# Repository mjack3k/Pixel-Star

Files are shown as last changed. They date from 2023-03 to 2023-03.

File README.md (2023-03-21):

# Pixel-Star
PCB star with RGB LEDs, xmas decoration

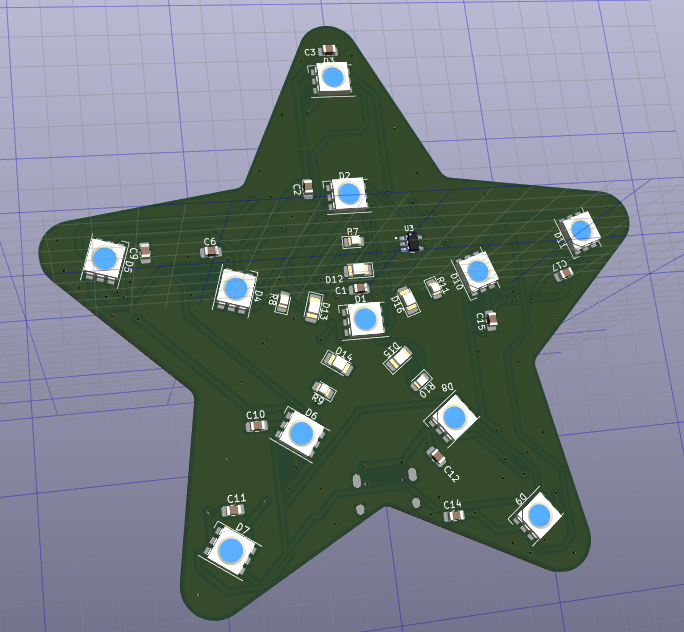
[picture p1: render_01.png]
PCB Render Kicad PCB 3D-render


With this project you can make a simple yet nice star-shaped PCB with a bunch of addressable LEDs.

It has STM32 microcontroller on board and this project provides software for it to drive the LEDs.
<br/><br/><br/>

In order to make it:

1. Download KiCAD 6, STM32CubeIDE, clone/download this project
2. Generate Gerber files according to your manufarcturer rules (for example [JLCPCB](https://support.jlcpcb.com/article/194-how-to-generate-gerber-and-drill-files-in-kicad-6))
3. Order the PCB
4. Order the parts (Kicad project contains links to all parts on lcsc)
5. Solder everything
6. Compile the STM32 project
7. Flash the firmware using ST-Link

A cable with 4-pin molex picoblade connector is needed to flash the board. 
[Like this one here](https://www.ebay.de/itm/174533296900)
<br/><br/><br/>

A quick test of the board:

Pixel-Star on Youtube (https://www.youtube.com/watch?v=iGwG598rLek)

<br/><br/><br/>

### Bill of Materials

|  Pos. | Name  | Link  | Amount  |
| --- | --- | --- | --- |
| 1.  | Capacitor 10µF 1206  | [Link](https://www.lcsc.com/product-detail/Multilayer-Ceramic-Capacitors-MLCC-SMD-SMT_Samsung-Electro-Mechanics-CL31B106KAHNNNE_C14860.html)  |  2  |
| 2.  | Capacitor 100nf 0805  | [Link](https://www.lcsc.com/product-detail/Multilayer-Ceramic-Capacitors-MLCC-SMD-SMT_CCTC-TCC0805X7R104K500DT_C282732.html)  | 17  |
| 3.  | Capacitor 4.7µF 1206  | [Link](https://www.lcsc.com/product-detail/Multilayer-Ceramic-Capacitors-MLCC-SMD-SMT_Samwha-Capacitor-CS3216X7R475K160NRI_C5189824.html)  | 1  |
| 4.  | WS2813E RGB LED  | [Link](https://www.lcsc.com/product-detail/Light-Emitting-Diodes-LED_Worldsemi-WS2813E_C160214.html)  | 11  |
| 5.  | LED 1206 Emerald  | [Link](https://www.lcsc.com/product-detail/Light-Emitting-Diodes-LED_XINGLIGHT-XL-3216UGC_C965825.html)  | 5  |
| 6.  | USB-C Connector  | [Link](https://www.lcsc.com/product-detail/USB-Connectors_SHOU-HAN-TYPE-C-16PIN-2MD-073_C2765186.html)  | 1  |
| 7.  | Picoblade 1x4 Connector  | [Link](https://www.lcsc.com/product-detail/Wire-To-Board-Wire-To-Wire-Connector_MOLEX-532610471_C240847.html)  | 1  |
| 8.  | Resistor 5.11k 0805  | [Link](https://www.lcsc.com/product-detail/Chip-Resistor-Surface-Mount_UNI-ROYAL-Uniroyal-Elec-0805W8F5111T5E_C46039.html)  | 2  |
| 9.  | Resistor 1k 0805  | [Link](https://www.lcsc.com/product-detail/Chip-Resistor-Surface-Mount_FOJAN-FRC0805F1001TS_C2907232.html)  | 2  |
| 10.  | Resistor 10k 0805  | [Link](https://www.lcsc.com/product-detail/Chip-Resistor-Surface-Mount_UNI-ROYAL-Uniroyal-Elec-0805W8F1002T5E_C17414.html)  | 2  |
| 11.  | Resistor 47 Ohm 0805  | [Link](https://www.lcsc.com/product-detail/Chip-Resistor-Surface-Mount_Walsin-Tech-Corp-WR08X47R0FTL_C168456.html)  | 5  |
| 12.  | Button  | [Link](https://www.lcsc.com/product-detail/Tactile-Switches_Korean-Hroparts-Elec-K2-1107ST-A4DW-06_C118141.html)  | 3  |
| 13.  | Voltage regulator 3.3V  | [Link](https://www.lcsc.com/product-detail/Linear-Voltage-Regulators-LDO_HEERMICR-AMS1117-3-3_C5199435.html)  | 1  |
| 14.  | MCU STM32G030  | [Link](https://www.lcsc.com/product-detail/Microcontroller-Units-MCUs-MPUs-SOCs_STMicroelectronics-STM32G030F6P6TR_C529330.html)  | 1  |
| 15.  | Level shifter  | [Link](https://www.lcsc.com/product-detail/Buffers-Drivers_Texas-Instruments-SN74LV1T34DBVR_C100024.html)  | 1  |

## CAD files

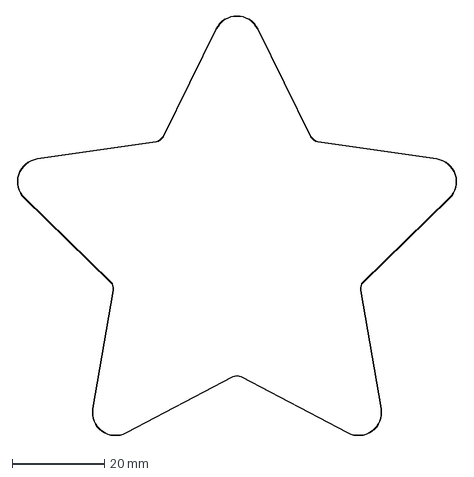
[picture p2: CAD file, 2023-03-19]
kicad/Stern.DXF
96.0 x 91.4 mm

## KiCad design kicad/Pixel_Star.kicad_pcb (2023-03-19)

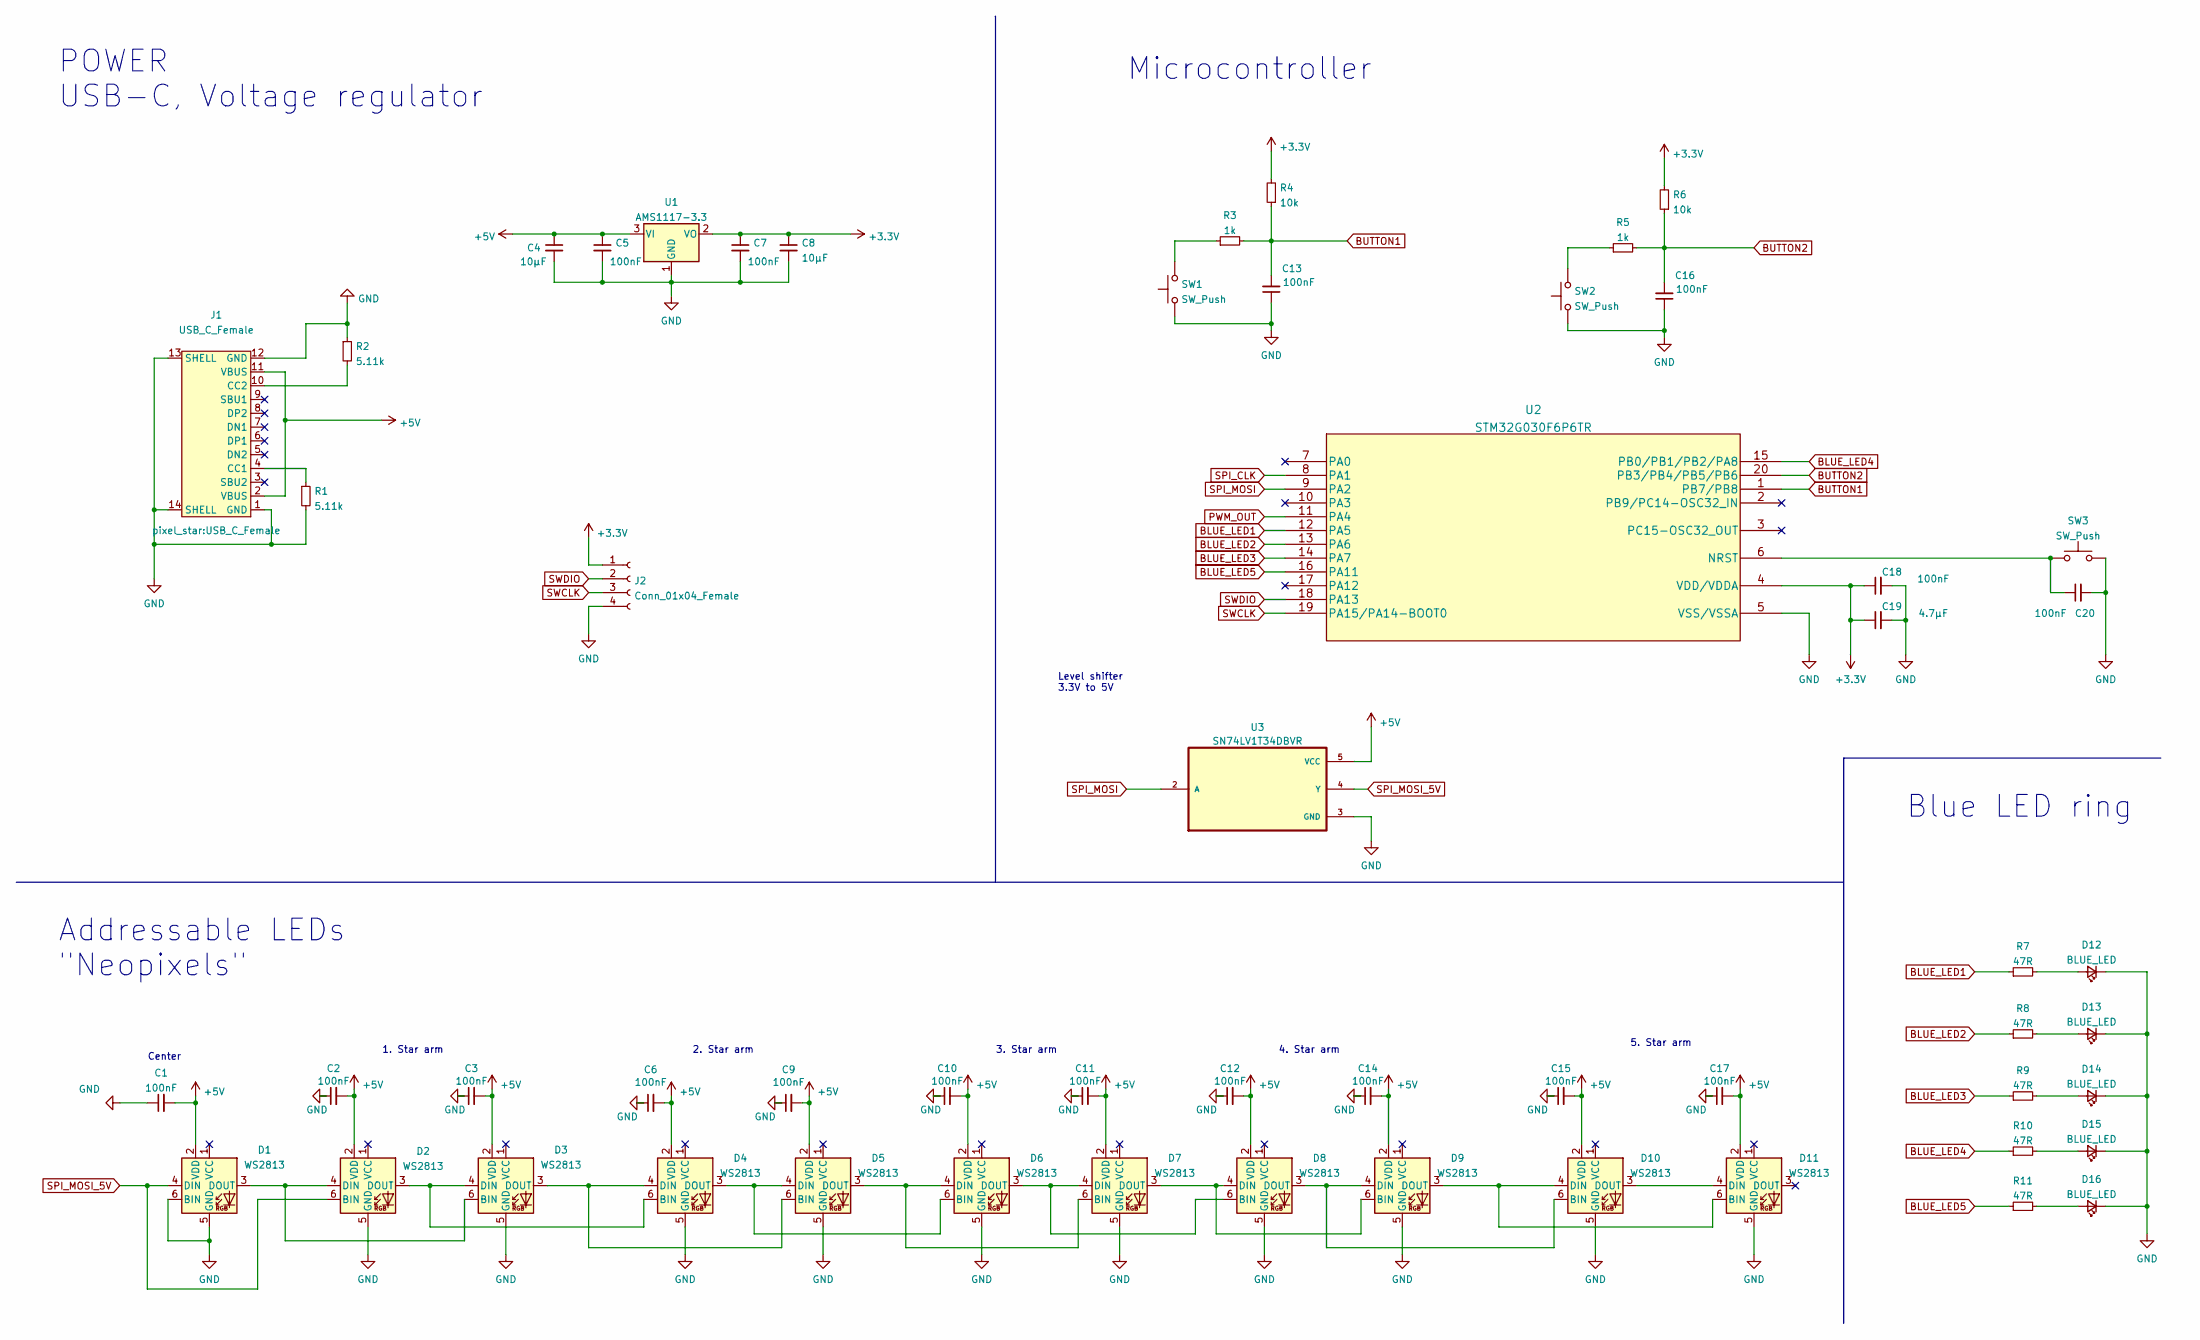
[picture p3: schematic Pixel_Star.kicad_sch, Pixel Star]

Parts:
C1, C2, C3, C5, C6, C7, C9, C10, C11, C12, C13, C14, C15, C16, C17, C18, C20: 100nF; C_0805_2012Metric_Pad1.18x1.45mm_HandSolder
C4, C8: 10µF; C_1206_3216Metric_Pad1.33x1.80mm_HandSolder
C19: 4.7µF; C_1206_3216Metric_Pad1.33x1.80mm_HandSolder
D1, D2, D3, D4, D5, D6, D7, D8, D9, D10, D11: WS2813; LED_WS2812_PLCC6_5.0x5.0mm_P1.6mm
D12, D13, D14, D15, D16: BLUE_LED; LED_1206_3216Metric_Pad1.42x1.75mm_HandSolder
J1: USB_C_Female
J2: Conn_01x04_Female; Molex_PicoBlade_53261-0471_1x04-1MP_P1.25mm_Horizontal
R1, R2: 5.11k; R_0805_2012Metric_Pad1.20x1.40mm_HandSolder
R3, R5: 1k; R_0805_2012Metric_Pad1.20x1.40mm_HandSolder
R4, R6: 10k; R_0805_2012Metric_Pad1.20x1.40mm_HandSolder
R7, R8, R9, R10, R11: 47R; LED_0805_2012Metric_Pad1.15x1.40mm_HandSolder
SW1, SW2, SW3: SW_Push; K2-1107ST-A4DW-06
U1: AMS1117-3.3; SOT-223-3_TabPin2
U2: STM32G030F6P6TR
U3: SN74LV1T34DBVR; SOT95P280X145-5N

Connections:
+3V3: C7.1, C8.1, C18.1, C19.1, J2.1, R4.2, R6.2, U1.2 (VO), U2.4 (VDD/VDDA)
+5V: C1.2, C2.2, C3.2, C4.1, C5.1, C6.2, C9.2, C10.2, C11.2, C12.2, C14.2, C15.2, C17.2, D1.2 (VDD), D2.2 (VDD), D3.2 (VDD), D4.2 (VDD), D5.2 (VDD), D6.2 (VDD), D7.2 (VDD), D8.2 (VDD), D9.2 (VDD), D10.2 (VDD), D11.2 (VDD), J1.2 (VBUS), J1.11 (VBUS), U1.3 (VI), U3.5 (VCC)
BLUE_LED1: R7.1, U2.12 (PA5)
BLUE_LED2: R8.1, U2.13 (PA6)
BLUE_LED3: R9.1, U2.14 (PA7)
BLUE_LED4: R10.1, U2.15 (PB0/PB1/PB2/PA8)
BLUE_LED5: R11.1, U2.16 (PA11)
BUTTON1: C13.2, R3.2, R4.1, U2.1 (PB7/PB8)
BUTTON2: C16.2, R5.2, R6.1, U2.20 (PB3/PB4/PB5/PB6)
GND: C1.1, C2.1, C3.1, C4.2, C5.2, C6.1, C7.2, C8.2, C9.1, C10.1, C11.1, C12.1, C13.1, C14.1, C15.1, C16.1, C17.1, C18.2, C19.2, C20.2, D1.5 (GND), D1.6 (BIN), D2.5 (GND), D3.5 (GND), D4.5 (GND), D5.5 (GND), D6.5 (GND), D7.5 (GND), D8.5 (GND), D9.5 (GND), D10.5 (GND), D11.5 (GND), D12.1 (K), D13.1 (K), D14.1 (K), D15.1 (K), D16.1 (K), J1.1 (GND), J1.12 (GND), J1.13 (SHELL), J1.14 (SHELL), J2.4, R1.2, R2.1, SW1.1, SW2.1, SW3.2, U1.1 (GND), U2.5 (VSS/VSSA), U3.3 (GND)
unnamed: C20.1, SW3.1, U2.6 (NRST)
unnamed: D1.3 (DOUT), D2.4 (DIN), D3.6 (BIN)
unnamed: D2.3 (DOUT), D3.4 (DIN), D4.6 (BIN)
unnamed: D3.3 (DOUT), D4.4 (DIN), D5.6 (BIN)
unnamed: D4.3 (DOUT), D5.4 (DIN), D6.6 (BIN)
unnamed: D5.3 (DOUT), D6.4 (DIN), D7.6 (BIN)
unnamed: D6.3 (DOUT), D7.4 (DIN), D8.6 (BIN)
unnamed: D7.3 (DOUT), D8.4 (DIN), D9.6 (BIN)
unnamed: D10.3 (DOUT), D11.4 (DIN)
unnamed: D9.3 (DOUT), D10.4 (DIN), D11.6 (BIN)
unnamed: D8.3 (DOUT), D9.4 (DIN), D10.6 (BIN)
unnamed: D12.2 (A), R7.2
unnamed: D13.2 (A), R8.2
unnamed: D14.2 (A), R9.2
unnamed: D15.2 (A), R10.2
unnamed: D16.2 (A), R11.2
unnamed: J1.4 (CC1), R1.1
unnamed: J1.10 (CC2), R2.2
unnamed: R3.1, SW1.2
unnamed: R5.1, SW2.2
PWM_OUT: U2.11 (PA4)
SPI_CLK: U2.8 (PA1)
SPI_MOSI: U2.9 (PA2), U3.2 (A)
SPI_MOSI_5V: D1.4 (DIN), D2.6 (BIN), U3.4 (Y)
SWCLK: J2.3, U2.19 (PA15/PA14-BOOT0)
SWDIO: J2.2, U2.18 (PA13)

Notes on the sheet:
Level shifter 3.3V to 5V
Addressable LEDs "Neopixels"
Microcontroller
3. Star arm
Center
Blue LED ring
POWER USB-C, Voltage regulator
4. Star arm
1. Star arm
5. Star arm
2. Star arm

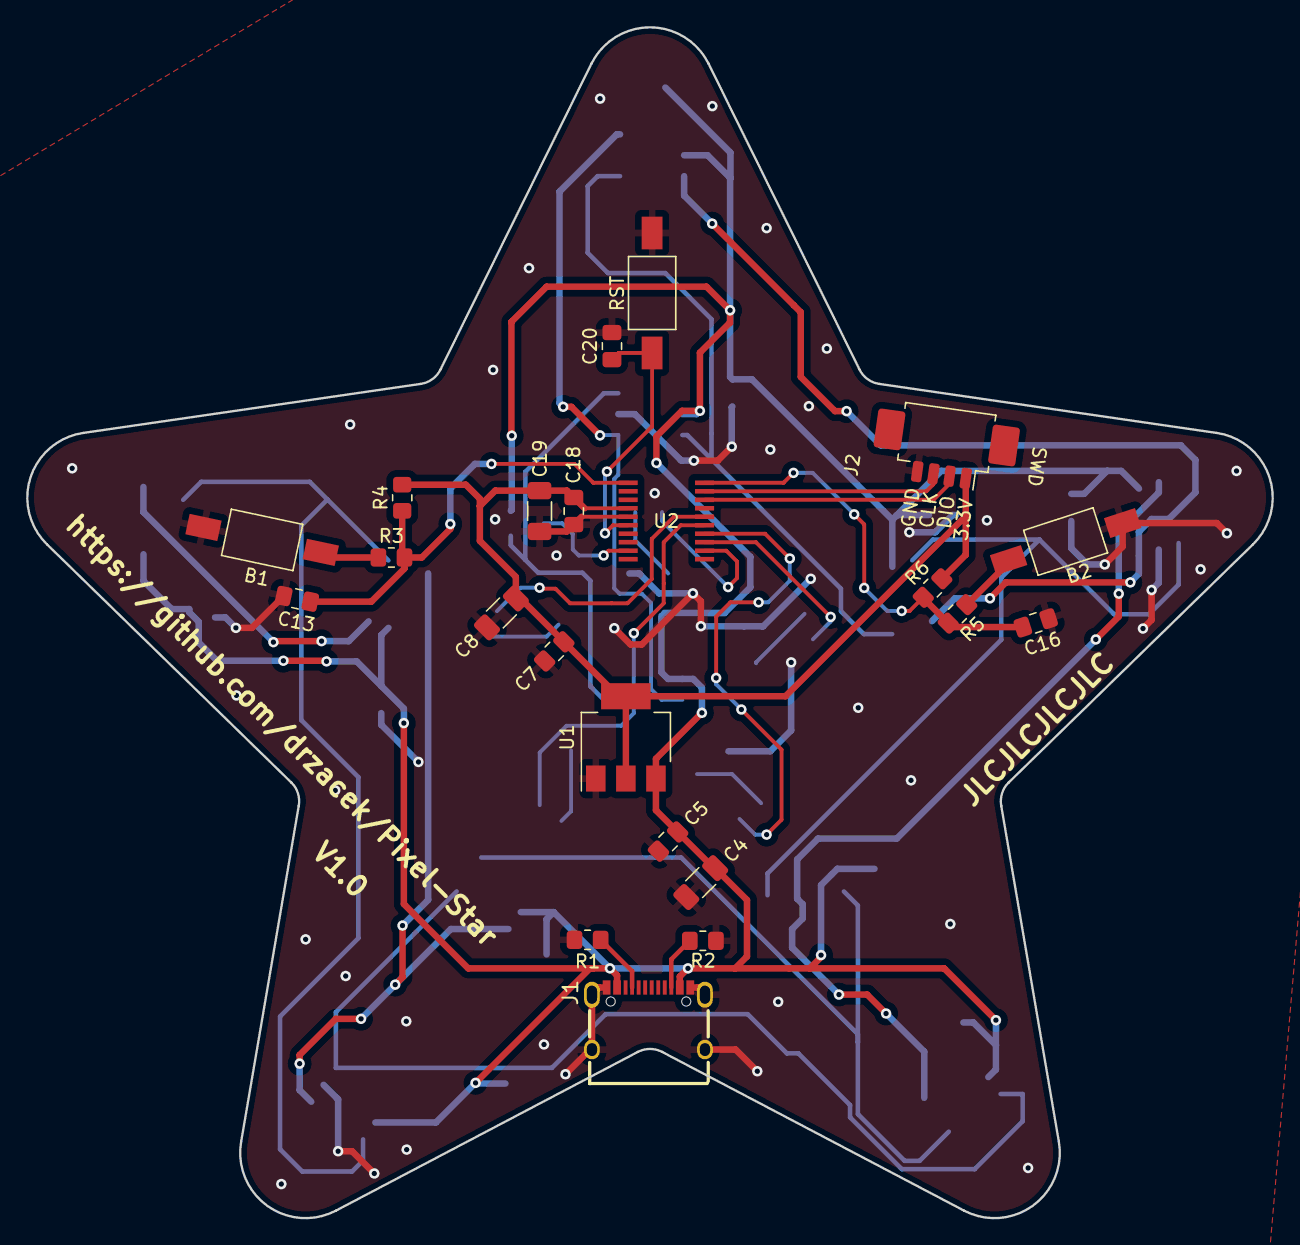
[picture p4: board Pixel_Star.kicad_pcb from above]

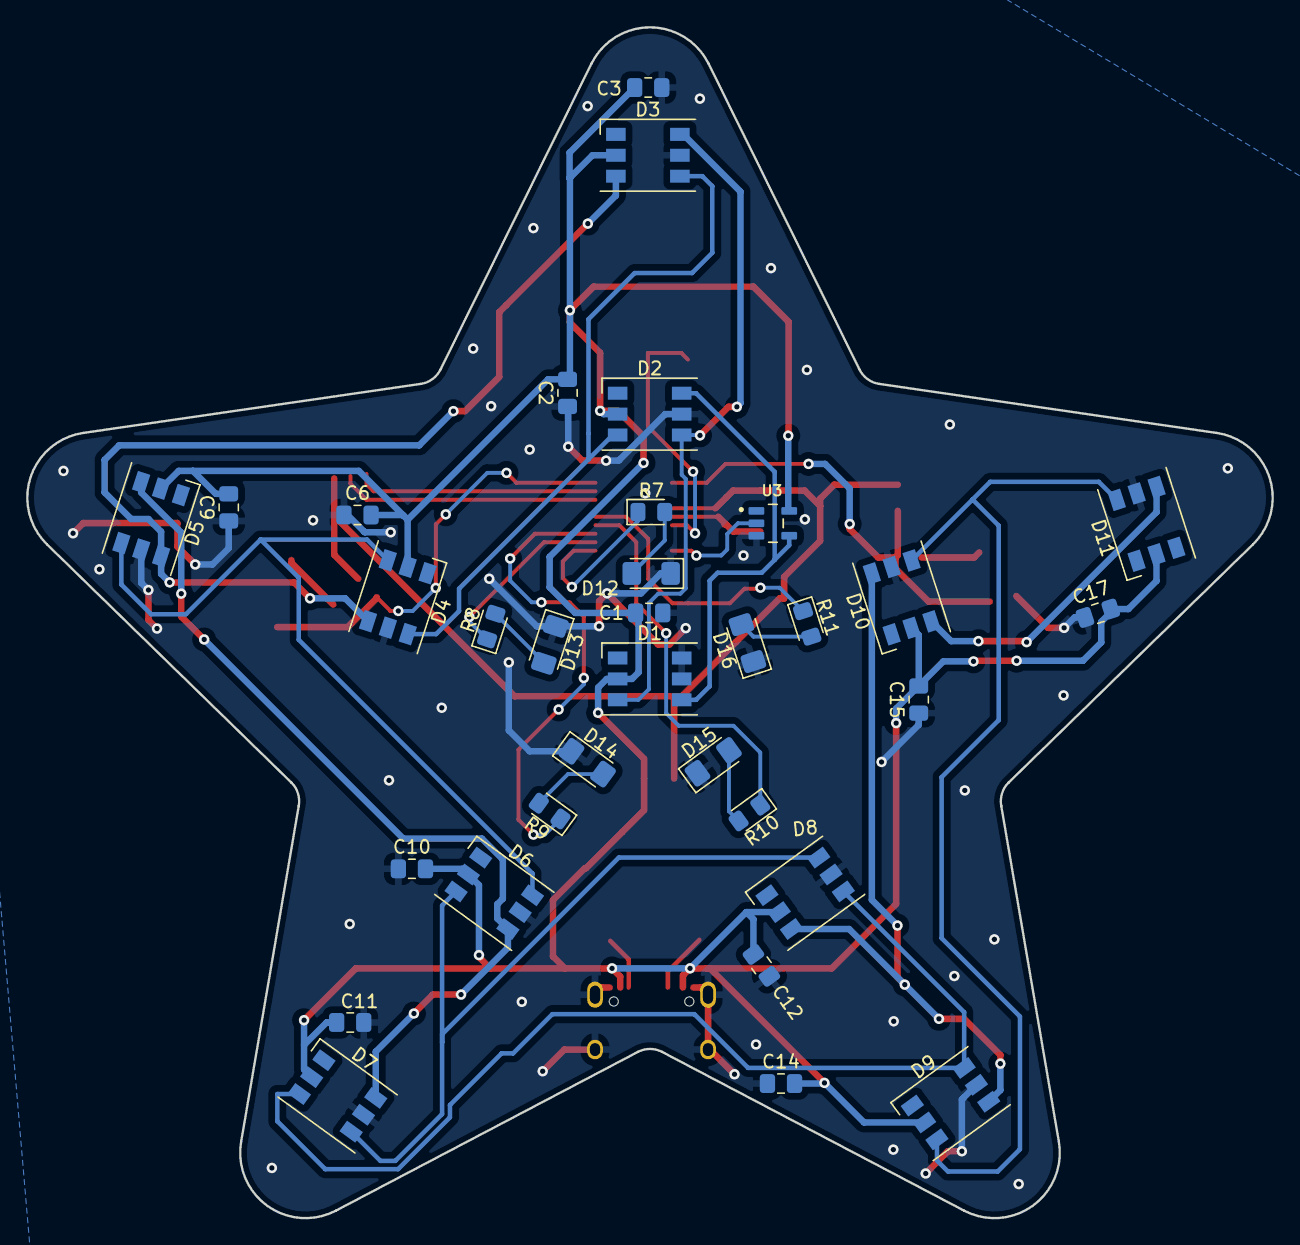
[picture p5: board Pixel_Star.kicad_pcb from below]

Board: 2 copper layers, 95.3 x 91.1 mm, 55 parts (33 on the bottom side), 34 nets.

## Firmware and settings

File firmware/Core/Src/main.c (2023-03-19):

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
/* Includes ------------------------------------------------------------------*/
#include "main.h"
#include "dma.h"
#include "spi.h"
#include "tim.h"
#include "gpio.h"

/* USER CODE BEGIN Includes */
#include "leds.h"
/* USER CODE END Includes */


void SystemClock_Config(void);
/**
  * @brief  The application entry point.
  * @retval int
  */
int main(void)
{
  /* MCU Configuration--------------------------------------------------------*/

  /* Reset of all peripherals, Initializes the Flash interface and the Systick. */
  HAL_Init();

  /* Configure the system clock */
  SystemClock_Config();

  /* Initialize all configured peripherals */
  MX_GPIO_Init();
  MX_DMA_Init();
  MX_SPI1_Init();
  MX_TIM17_Init();
  /* Infinite loop */
  /* USER CODE BEGIN WHILE */

  ws2813_init(hspi1);

  int8_t effectNumber = 0;				// used to switch between different effects (animations)
  uint32_t lastButton1PressTick = 0;	// last button press occured at X - used to filter out bouncing
  uint32_t lastButton2PressTick = 0;	// last button press occured at X - used to filter out bouncing
  uint8_t lastButton1State = 0;
  uint8_t lastButtonState = 0;


  while (1)
  {
	  HAL_Delay(1000/50);

	  // Handle buttons and effect changes
	  if (!HAL_GPIO_ReadPin(BUTTON1_GPIO_Port, BUTTON1_Pin))
	  {
		  if ((uint32_t)((HAL_GetTick() - lastButton1PressTick)) > 200)
		  {
			  lastButton1PressTick = HAL_GetTick();

			  effectNumber++;
		  }
	  }

	  if (!HAL_GPIO_ReadPin(BUTTON2_GPIO_Port, BUTTON2_Pin))
	  {
		  if ((uint32_t)((HAL_GetTick() - lastButton2PressTick)) > 200)
		  {
			  lastButton2PressTick = HAL_GetTick();

			  effectNumber--;
		  }
	  }

	  if (effectNumber > 5)
	  {
		  effectNumber = 0;
	  }

	  if (effectNumber < 0)
	  {
		  effectNumber = 5;
	  }

	  // WS2813 test
	  ws2813_clearAllLed();	// Set all LEDs to 0

	  switch(effectNumber)
	  {
	  case 5:
		  led_effect_5();
		  break;

	  case 4:
		  led_effect_4();
		  break;

	  case 3:
		  led_effect_3();
		  break;

	  case 2:
		  led_effect_2();
		  break;

	  case 1:
		  led_effect_1();
		  break;

	  case 0:
	  default:
		  led_effect_0();
		  break;
	  }


	  ws2813_sendLEDs();



    /* USER CODE END WHILE */

    /* USER CODE BEGIN 3 */
  }
  /* USER CODE END 3 */
}

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


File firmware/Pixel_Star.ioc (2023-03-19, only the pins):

Mcu.UserName=STM32G030F6Px
PA1.Signal=SPI1_SCK
PA13.Signal=SYS_SWDIO
PA14-BOOT0.Signal=SYS_SWCLK
PA2.Signal=SPI1_MOSI
PA5.GPIO_Label=BLU_LED1
PA5.Signal=GPIO_Output
PA6.GPIO_Label=BLU_LED2
PA6.Signal=GPIO_Output
PA7.GPIO_Label=BLU_LED3
PA7.Signal=GPIO_Output
PA8.GPIO_Label=BLU_LED4
PA8.Signal=GPIO_Output
PB6.GPIO_Label=BUTTON2
PB6.Signal=GPIO_Input
PB8.GPIO_Label=BUTTON1
PB8.Signal=GPIO_Input

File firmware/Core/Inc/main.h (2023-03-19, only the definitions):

#define BUTTON1_Pin GPIO_PIN_8
#define BUTTON1_GPIO_Port GPIOB
#define BLU_LED1_Pin GPIO_PIN_5
#define BLU_LED1_GPIO_Port GPIOA
#define BLU_LED2_Pin GPIO_PIN_6
#define BLU_LED2_GPIO_Port GPIOA
#define BLU_LED3_Pin GPIO_PIN_7
#define BLU_LED3_GPIO_Port GPIOA
#define BLU_LED4_Pin GPIO_PIN_8
#define BLU_LED4_GPIO_Port GPIOA
#define BLU_LED5_Pin GPIO_PIN_11
#define BLU_LED5_GPIO_Port GPIOA
#define BUTTON2_Pin GPIO_PIN_6
#define BUTTON2_GPIO_Port GPIOB

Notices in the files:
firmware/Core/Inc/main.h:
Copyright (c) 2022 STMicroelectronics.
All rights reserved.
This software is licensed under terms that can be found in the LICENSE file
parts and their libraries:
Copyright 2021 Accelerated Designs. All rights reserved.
